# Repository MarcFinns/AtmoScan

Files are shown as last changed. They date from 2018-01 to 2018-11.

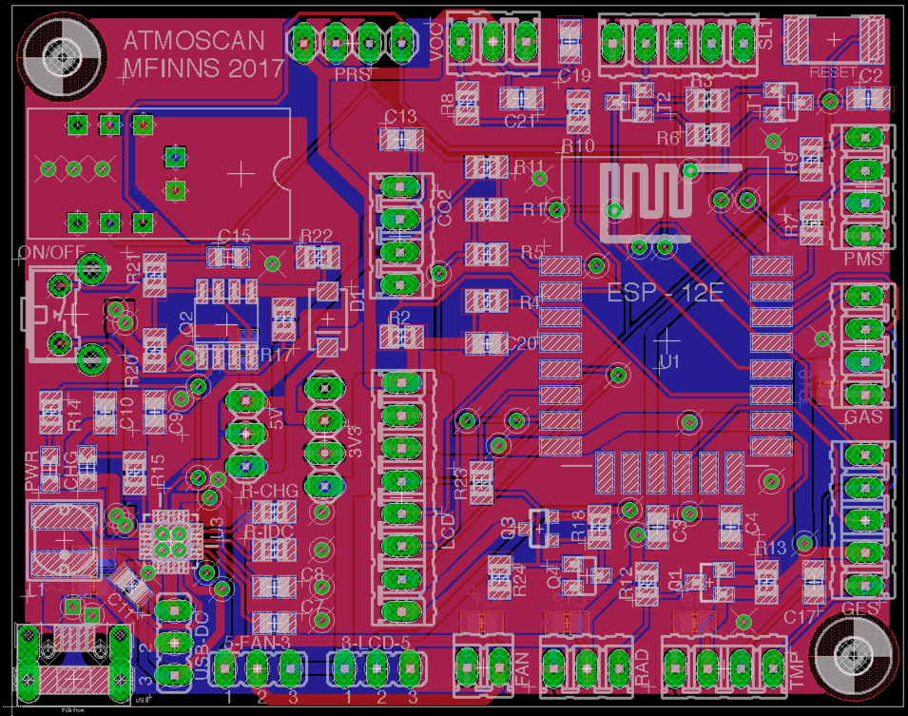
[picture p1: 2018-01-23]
Hardware & Configuration/Atmoscan PCB.jpg

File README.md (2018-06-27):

## AtmoScan

Instructable can be found [HERE](https://www.instructables.com/id/AtmoScan/).  
See it in action in this [VIDEO](https://www.youtube.com/watch?v=iyFuKU8ZcuA).

**What's new** - Atmoscan is evolving:

* Some small hardware changes improved the original design, including the ability to **turn off itself from software**, remediating one of the biggest drawbacks of the design - how to handle low battery. 
* Command added to the setup **menu to turn off the device**
* White screen with low battery issue **mitigation**
* A PCB v2 design is now published together with a guide to easily **apply the change to boards V1.0.**
* Battery pack now based on 5 x 18650 Li-ion in "olympic circles" configuration. Way more performant and reliable than the chinese Li-Po pack
* Repositioning of the CO2 sensor, to completely separate the temperature sensor from any potential heat source
* CAD files for the **complete enclosure**, with improved design

Atmoscan might be (to my knowledge at least) the first ESP8266 application that **uses all GPIOs**, including those that allegedly cannot be used.

**ATMOSCAN** is a multisensor device that measures:

* Temperature
* Humidity
* Pressure
* CO2
* CO
* NO2
* VOC (Air Quality indicator)
* PM 01
* PM25
* PM10
* PM 01
* Radiation

It has an LCD color display, it is gesture controlled and it posts to ThingSpeak (or others) via MQTT, but can properly handle disconnected operations. With a rechargeable battery it lasts a full day when disconnected from power.

It uses a a multitasking cooperative framework and is very responsive to user input while sampling sensors, handling UI, posting to MQTT. I believe it squeezes quite a bit out of the tiny ESP8266...

It integrates a number of open source libraries and leverages internet web services. I started buiding the software with a proper OO application framework in mind and you can find artifacts of it... but never had the time to properly finish it the way i started, so i quickly completed it with way too many hacks. Therefore code could be way better (not properly commented, test code, residuals...).  If anyone is interested in contributing, it's very welcome.

I still have a few PCBs that i am happy to give away to those who want to build it and contribute to it.

### MAIN FEATURES
```
* Color screen
* Gesture control
* Location awareness
* ThingSpeak logging        
* Gracefully handles connected and disconnected operation
* 24h Rechargeable battery
* OTA updates
* Bonus features:
	* Weather Station
	* Plane Spotter

```

### CREDITS

**INCLUDES CODE & LIBRARIES FROM**

```
Adafruit
Arcao
Bblanchon
Bodmer
ClosedCube
Gmag11
Knolleary	
Lucadentella
Seeed
Squix78
Tzapu
Wizard97	
```

**INTEGRATES WEB SERVICES FROM**

```
Adsbexchange.com
GeoNames.org
Google.com
Mylnikov.org
Timezonedb.com
Wunderground.com
```

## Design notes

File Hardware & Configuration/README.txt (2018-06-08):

*IMPORTANT NOTES*

1) HARDWARE
Atmoscan is built with an integrated custom board but can also be built with standard components if you are willing to give up on battery power, size etc. Specifically the prototype was built with only the following components:
- NodeMCU
- Level shifter

2) FLASHING
As the serial port is occupied by a sensor, debugging and programming that way is impractical after assembly as it would require detaching the sensor. Therefore the sketch supports SYSLOG debugging and OTA updates.
The ATMOSCAN binary is over 700Kb and ArduinoOTA requires the program space to be at least twice that size, which rules out the "4M (3M SPIFFS)" option.
However, the standard "4M (1M SPIFFS)" option is also unsuitable as the SPIFFS partition would be insufficient for the graphical resources related to weather station, plane spotter and for the onfing file.
THE SOLUTION: create a custom configuration "4M (2M SPIFFS)".

To do so:
a) Install ESP8266 Arduino support from Github (not from board manager)
b) Add the lines to boards.txt as specified in the accompanying file "mod to boards.txt"
c) Copy the "eagle.flash.4m2m.ld" file to the location ...Arduino/Hardware/esp8266com/esp8266/tools/sdk/ld/
d) Restart Arduino IDE and under NODEMCU 1.0 a new options will appear "4M (2M SPIFFS)"

3) NECESSARY configuration

a) The TFT library (https://github.com/Bodmer/TFT_eSPI) has a config file (User_Setup.h) that MUST be edited to define 
- which GPIOs are used for the display 
- the SPI clock frequency.

While SPI could theoretically run up to 40MHz, it is better to keep it lower, say 20MHz, especially if the cables to the display are not very short. Skipping this step *WILL* make the sketch fail. An example file is in this directory, but make sure you edit your own should the format change in new versions of the library

b) Some #DEFINE statements should be reviewed in the GlobalDefinitions.h file, as follows.

// Used to test board without sensor processes running 
#define ENABLE_SENSORS
 
// Enables the ability to turn itself off. NOTE: requires PCB 2.0 -OR- the appropriate modification 
#define KILL_INSTALLED

// Used to turn on debug log over syslog 
#define DEBUG_SYSLOG
 
// Used to turn on SOME log over serial 
// WARNING - this was used during development and can be used to debug the portions of the sketch that run BEFORE TCP/IP connection is available, but can't be used in the fully assembled system (as serial port is used for a sensor)
#define DEBUG_SERIAL

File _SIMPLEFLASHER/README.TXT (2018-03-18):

This sketch can be used for first flash of the board. Useful to make sure it works, without the complexity of sensors.
1. Configure ESP memory as 4M (2M SPIFFS)
2. Upload this sketch with an FTDI cable connected to the J7 connector
Upon reboot, the board will create a WiFI access point and it accepts OTA updates.

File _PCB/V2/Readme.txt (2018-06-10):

IMPORTANT

The V2 schematic has been tested by modifying a V1 PCB and it works. The V2 PCB has been routed but has not been manufactured. I was happy enough with the modded V1. 
However i thought that if someone wanted to make Atmoscan from scratrch, it would be a good idea to provide the latest schematic with a companion PCB.
THEREFORE... before sending it blindly to your manufacturer of choice, I suggest you double check it.
Please contact me should you find any glitches. 
Happy soldering!

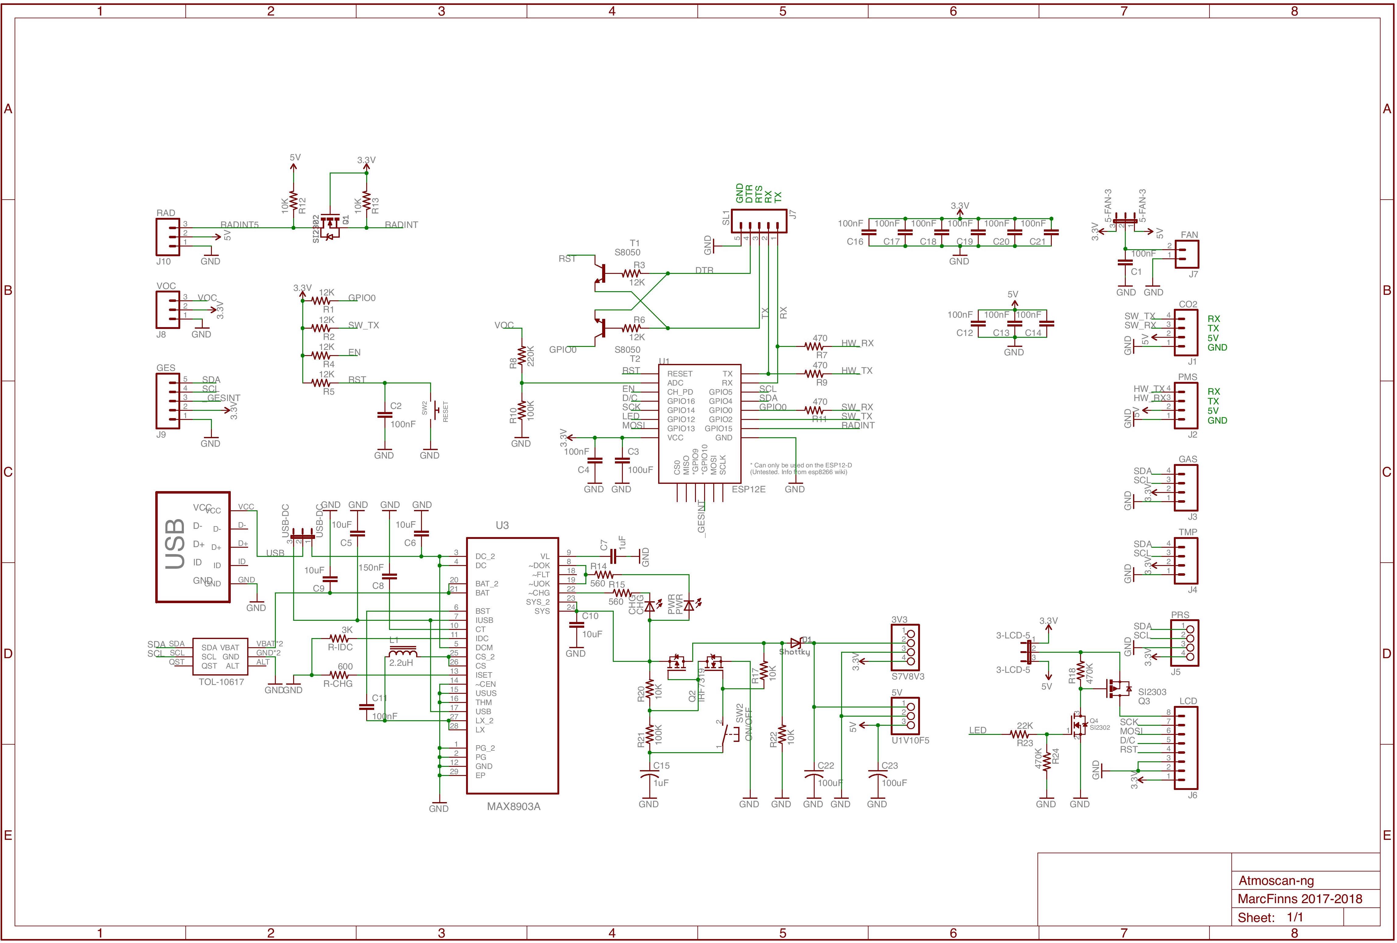
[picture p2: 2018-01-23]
Hardware & Configuration/Atmoscan Schematic.jpeg

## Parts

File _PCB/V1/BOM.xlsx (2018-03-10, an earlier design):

Part | Value | Device | Package | Description
3-LCD-5 | 3-LCD-5 | JP2E | JP2 | JUMPER
3V3 | S7V8V3 | PINHD-1X4 | 1X04 | PIN HEADER
5-FAN-3 | 5-FAN-3 | JP2E | JP2 | JUMPER
5V | U1V10F5 | PINHD-1X3 | 1X03 | PIN HEADER
C1 | 100nF | C-EUC0805 | C0805 | CAPACITOR, European symbol
C2 | 100nF | C-EUC0805 | C0805 | CAPACITOR, European symbol
C3 | 100uF | C-EUC0805 | C0805 | CAPACITOR, European symbol
C4 | 100nF | C-EUC0805 | C0805 | CAPACITOR, European symbol
C5 | 10uF | C-EUC0805 | C0805 | CAPACITOR, European symbol
C6 | 10uF | C-EUC0805 | C0805 | CAPACITOR, European symbol
C7 | 1uF | C-EUC0805 | C0805 | CAPACITOR, European symbol
C8 | 150nF | C-EUC0805 | C0805 | CAPACITOR, European symbol
C9 | 10uF | C-EUC0805 | C0805 | CAPACITOR, European symbol
C10 | 10uF | C-EUC0805 | C0805 | CAPACITOR, European symbol
C11 | 100nF | C-EUC0805 | C0805 | CAPACITOR, European symbol
C12 | 100nF | C-EUC0805 | C0805 | CAPACITOR, European symbol
C13 | 100nF | C-EUC0805 | C0805 | CAPACITOR, European symbol
C14 | 100nF | C-EUC0805 | C0805 | CAPACITOR, European symbol
C15 | 1uF | C-USC0805K | C0805K | CAPACITOR, American symbol
C16 | 100nF | C-EUC0805 | C0805 | CAPACITOR, European symbol
C17 | 100nF | C-EUC0805 | C0805 | CAPACITOR, European symbol
C18 | 100nF | C-EUC0805 | C0805 | CAPACITOR, European symbol
C19 | 100nF | C-EUC0805 | C0805 | CAPACITOR, European symbol
C20 | 100nF | C-EUC0805 | C0805 | CAPACITOR, European symbol
C21 | 100nF | C-EUC0805 | C0805 | CAPACITOR, European symbol
C22 | 100uF | C-USC0805K | C0805K | CAPACITOR, American symbol
C23 | 100uF | C-USC0805K | C0805K | CAPACITOR, American symbol
CHG | CHG | LEDCHIPLED_0805 | CHIPLED_0805 | LED
CO2 | J1 | M04 | 04P | AMP QUICK CONNECTOR
D1 | Shottky | DIODE-SCHOTTKYSMA-403D | SMA-403D | Commonly MBRA140.
FAN | J7 | M02 | 02P | AMP QUICK CONNECTOR
GAS | J3 | M04 | 04P | AMP QUICK CONNECTOR
GES | J9 | M05 | 05P | AMP QUICK CONNECTOR
L1 | 2.2uH | SDR0503 | SDR0503 | POWER INDUCTOR
LCD | J6 | M08 | 08P | AMP QUICK CONNECTOR
ON/OFF | SW2 | 31-XX | B3F-31XX | OMRON SWITCH
PMS | J2 | M04 | 04P | AMP QUICK CONNECTOR
PRS | J5 | PINHD-1X4 | 1X04 | PIN HEADER
PWR | PWR | LEDCHIPLED_0805 | CHIPLED_0805 | LED
Q1 | SI2302 | FET-NMOS-BSS138 | SOT-23
Q2 | IRF7319 | IRF7319 | SO08-IRF | Complimentary Half Bridge HEXFET Power MOSFET
Q3 | SI2303 | NX3008PBK | SOT23-3 | MOSFET - P Channel
Q4 | SI2302 | MOSFET-NREFLOW | SOT23 | N-Channel Mosfet
R-CHG | 600 | R-US_M0805 | M0805 | RESISTOR, American symbol
R-IDC | 3K | R-US_M0805 | M0805 | RESISTOR, American symbol
R1 | 12K | R-US_M0805 | M0805 | RESISTOR, American symbol
R2 | 12K | R-US_M0805 | M0805 | RESISTOR, American symbol
R3 | 12K | R-US_M0805 | M0805 | RESISTOR, American symbol
R4 | 12K | R-US_M0805 | M0805 | RESISTOR, American symbol
R5 | 12K | R-US_M0805 | M0805 | RESISTOR, American symbol
R6 | 12K | R-US_M0805 | M0805 | RESISTOR, American symbol
R7 | 470 | R-US_M0805 | M0805 | RESISTOR, American symbol
R8 | 220K | R-US_M0805 | M0805 | RESISTOR, American symbol
R9 | 470 | R-US_M0805 | M0805 | RESISTOR, American symbol
R10 | 100K | R-US_M0805 | M0805 | RESISTOR, American symbol
R11 | 470 | R-US_M0805 | M0805 | RESISTOR, American symbol
R12 | 10K | R-US_M0805 | M0805 | RESISTOR, American symbol
R13 | 10K | R-US_M0805 | M0805 | RESISTOR, American symbol
R14 | 560 | R-US_M0805 | M0805 | RESISTOR, American symbol
R15 | 560 | R-US_M0805 | M0805 | RESISTOR, American symbol
R17 | 10K | R-US_M0805 | M0805 | RESISTOR, American symbol
R18 | 470K | R-US_M0805 | M0805 | RESISTOR, American symbol
R20 | 10K | R-US_M0805 | M0805 | RESISTOR, American symbol
R21 | 100K | R-US_M0805 | M0805 | RESISTOR, American symbol
R22 | 10K | R-US_M0805 | M0805 | RESISTOR, American symbol
R23 | 22K | R-US_M0805 | M0805 | RESISTOR, American symbol
R24 | 470K | R-US_M0805 | M0805 | RESISTOR, American symbol
RAD | J10 | M03 | 03P | AMP QUICK CONNECTOR
RESET | SW2 | SWITCH_PUSHBUTTONC&K_KSS | BTN_CK_KSS | Buttons
SL1 | J7 | M05 | 05P | AMP QUICK CONNECTOR
T1 | S8050 | BC846 | SOT23 | NPN TRANSISTOR
T2 | S8050 | BC846 | SOT23 | NPN TRANSISTOR
TMP | J4 | M04 | 04P | AMP QUICK CONNECTOR
U1 | ESP12E | ESP12ESMD | ESP12E-SMD | ESP12E Module
U2 | TOL-10617 | TOL-10617 | TOL-10617
U3 | MAX8903A | MAX8903AETI+ | QFN40P400X400X80-29N | 2A 1-Cell Li+ DC-DC Chargers for USB and Adapter Power
USB | MICRO-USB-B | MICRO-USB-B | MICRO_USB_4_LEGS
USB-DC | USB-DC | JP2E | JP2 | JUMPER
VOC | J8 | M03 | 03P | AMP QUICK CONNECTOR

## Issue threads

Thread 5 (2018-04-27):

File missing during compilation

Tokn59, 2018-04-27:
During compilation of the Atmoscan 1.4 sketch the following error is produced :
sketch\esp32-hal-i2c.c:16:23: fatal error: esp32-hal.h: No such file or directory

 #include "esp32-hal.h"

                       ^

compilation terminated.

Multiple libraries were found for "SD.h"
 Used: C:\Users\Tony\AppData\Local\Arduino15\packages\esp8266\hardware\esp8266\2.4.0-rc2\libraries\SD
 Not used: C:\Program Files (x86)\Arduino\libraries\SD
exit status 1
Error compiling for board Generic ESP8266 Module.

Any idea how to solve this ?

Thanks and kind regards,

Tony

per1234, 2018-04-27:
Why do you have a file named esp32-hal-i2c.c in your sketch folder? There is no file of that name in this repository.

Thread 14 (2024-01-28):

VBat conductor shorted to ground on PCB

schofiel, 2024-01-28:
The VBat conductor between the Sparkfun TOL 10617 battery positive pin and the BAT/BAT 2 inputs to the MAX8903A charge management IC U2 (pins 21 & 20) is shorted to ground on the PCB by a flood-filled polygon zone. This is on the top copper layer. The design rule checker does not mark the intersection of the polygon with the track as a problem.

The net result is that U2 (MAX8903A) fails to regulate properly and the board fails to operate (dead short/no voltage). With the battery pack connected, the pack delivers peak current (3x 5A) to ground, with the associated fire risk due to battery failure.

An image of the polygon:

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

An image of the resulting top copper gerber:

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

The work-around is a careful scalpel cut along the edge of the track to separate the polygon from ground.

schofiel, 2024-01-28:
Should note that this is for the V2 board version.

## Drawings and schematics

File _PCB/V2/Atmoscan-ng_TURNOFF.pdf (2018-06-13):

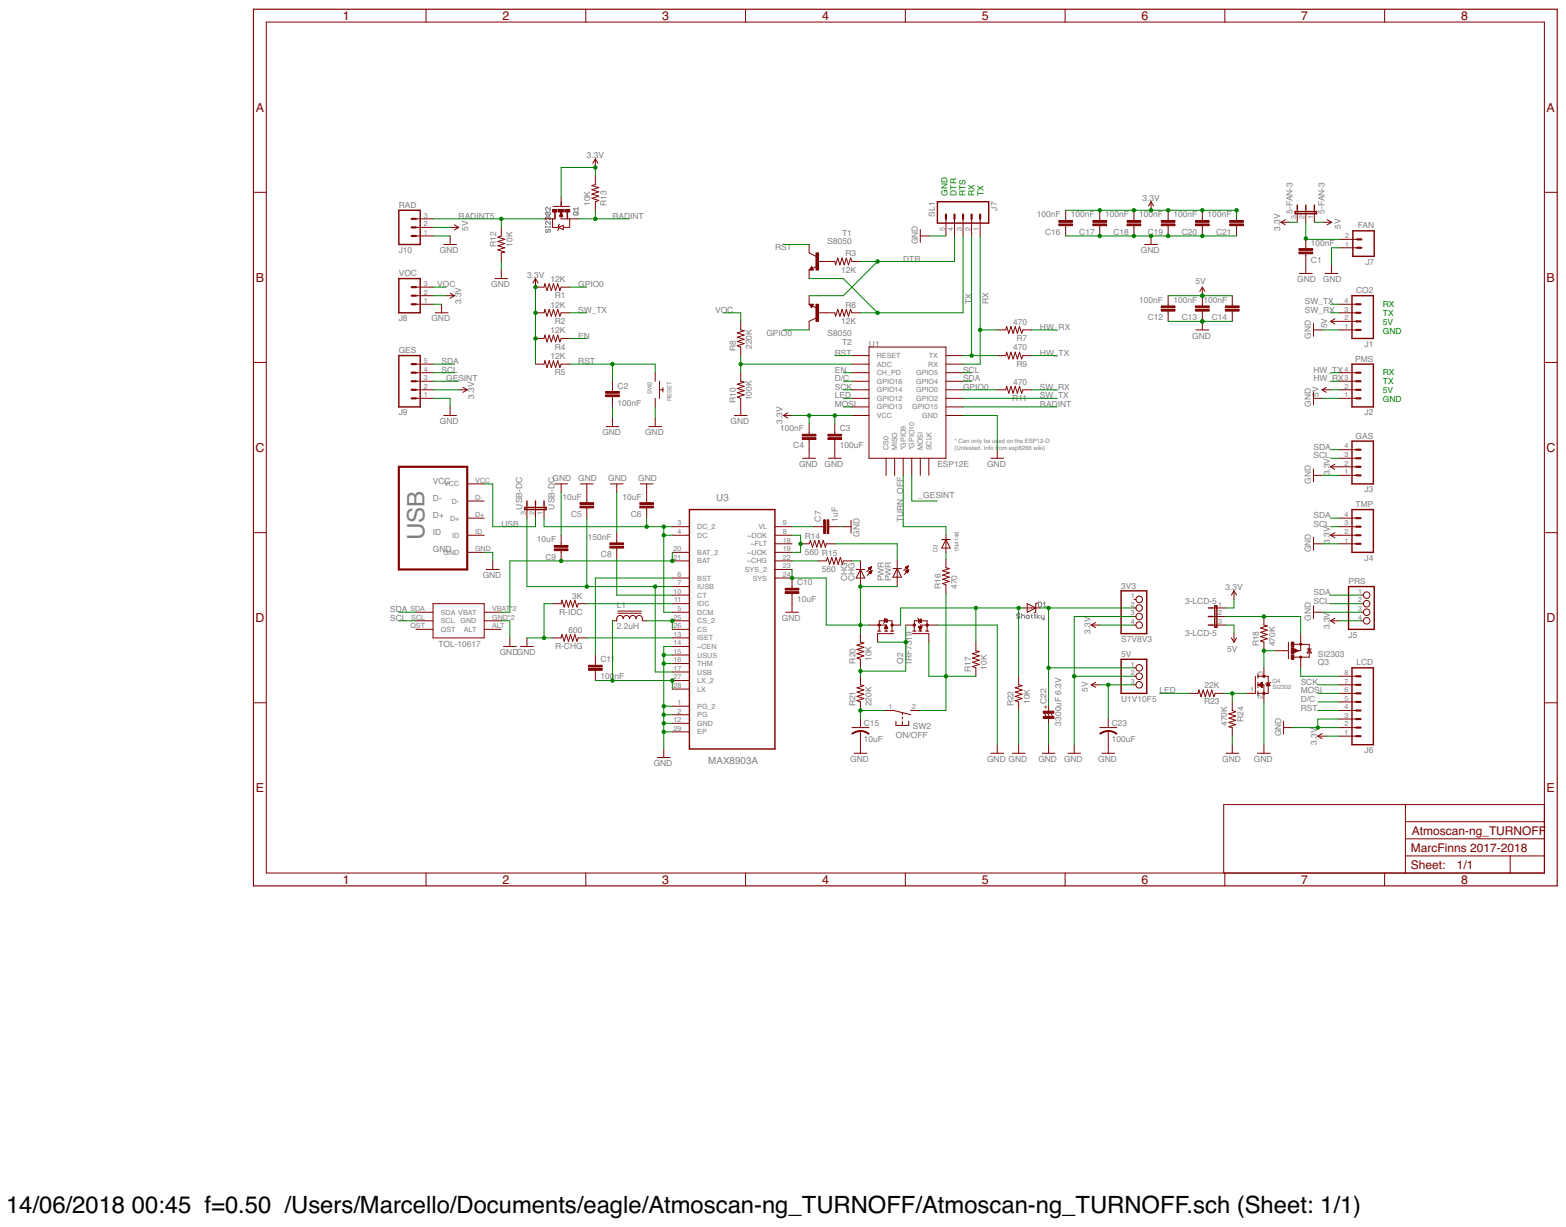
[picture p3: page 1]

* Can only be used on the ESP12-D
(Untested. Info from esp8266 wiki)
ESP12E

14/06/2018 00:45 f=0.50 /Users/Marcello/Documents/eagle/Atmoscan-ng_TURNOFF/Atmoscan-ng_TURNOFF.sch (Sheet: 1/1)

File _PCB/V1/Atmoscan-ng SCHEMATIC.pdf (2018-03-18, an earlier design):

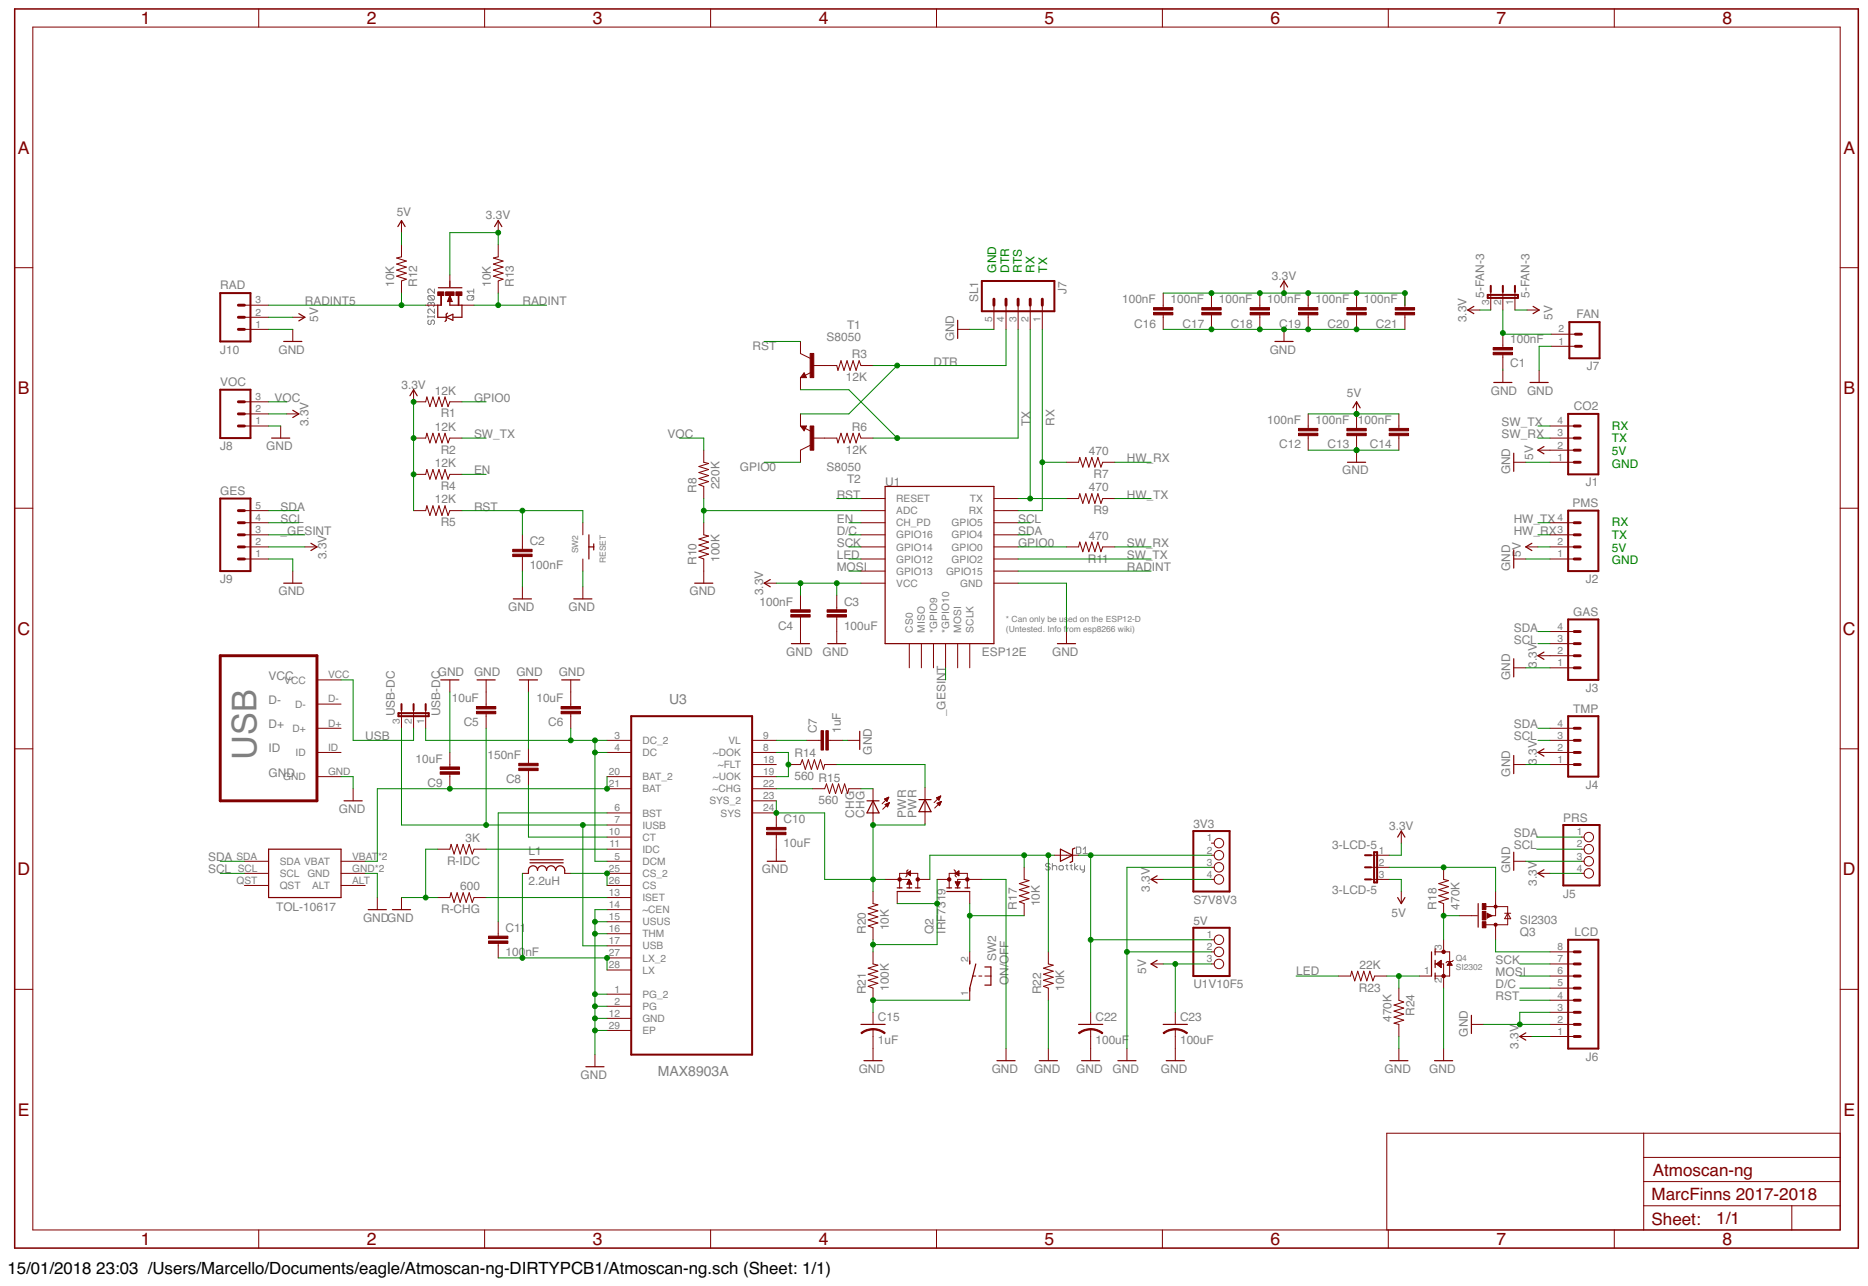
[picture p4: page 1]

* Can only be used on the ESP12-D
(Untested. Info from esp8266 wiki)
ESP12E

15/01/2018 23:03 /Users/Marcello/Documents/eagle/Atmoscan-ng-DIRTYPCB1/Atmoscan-ng.sch (Sheet: 1/1)

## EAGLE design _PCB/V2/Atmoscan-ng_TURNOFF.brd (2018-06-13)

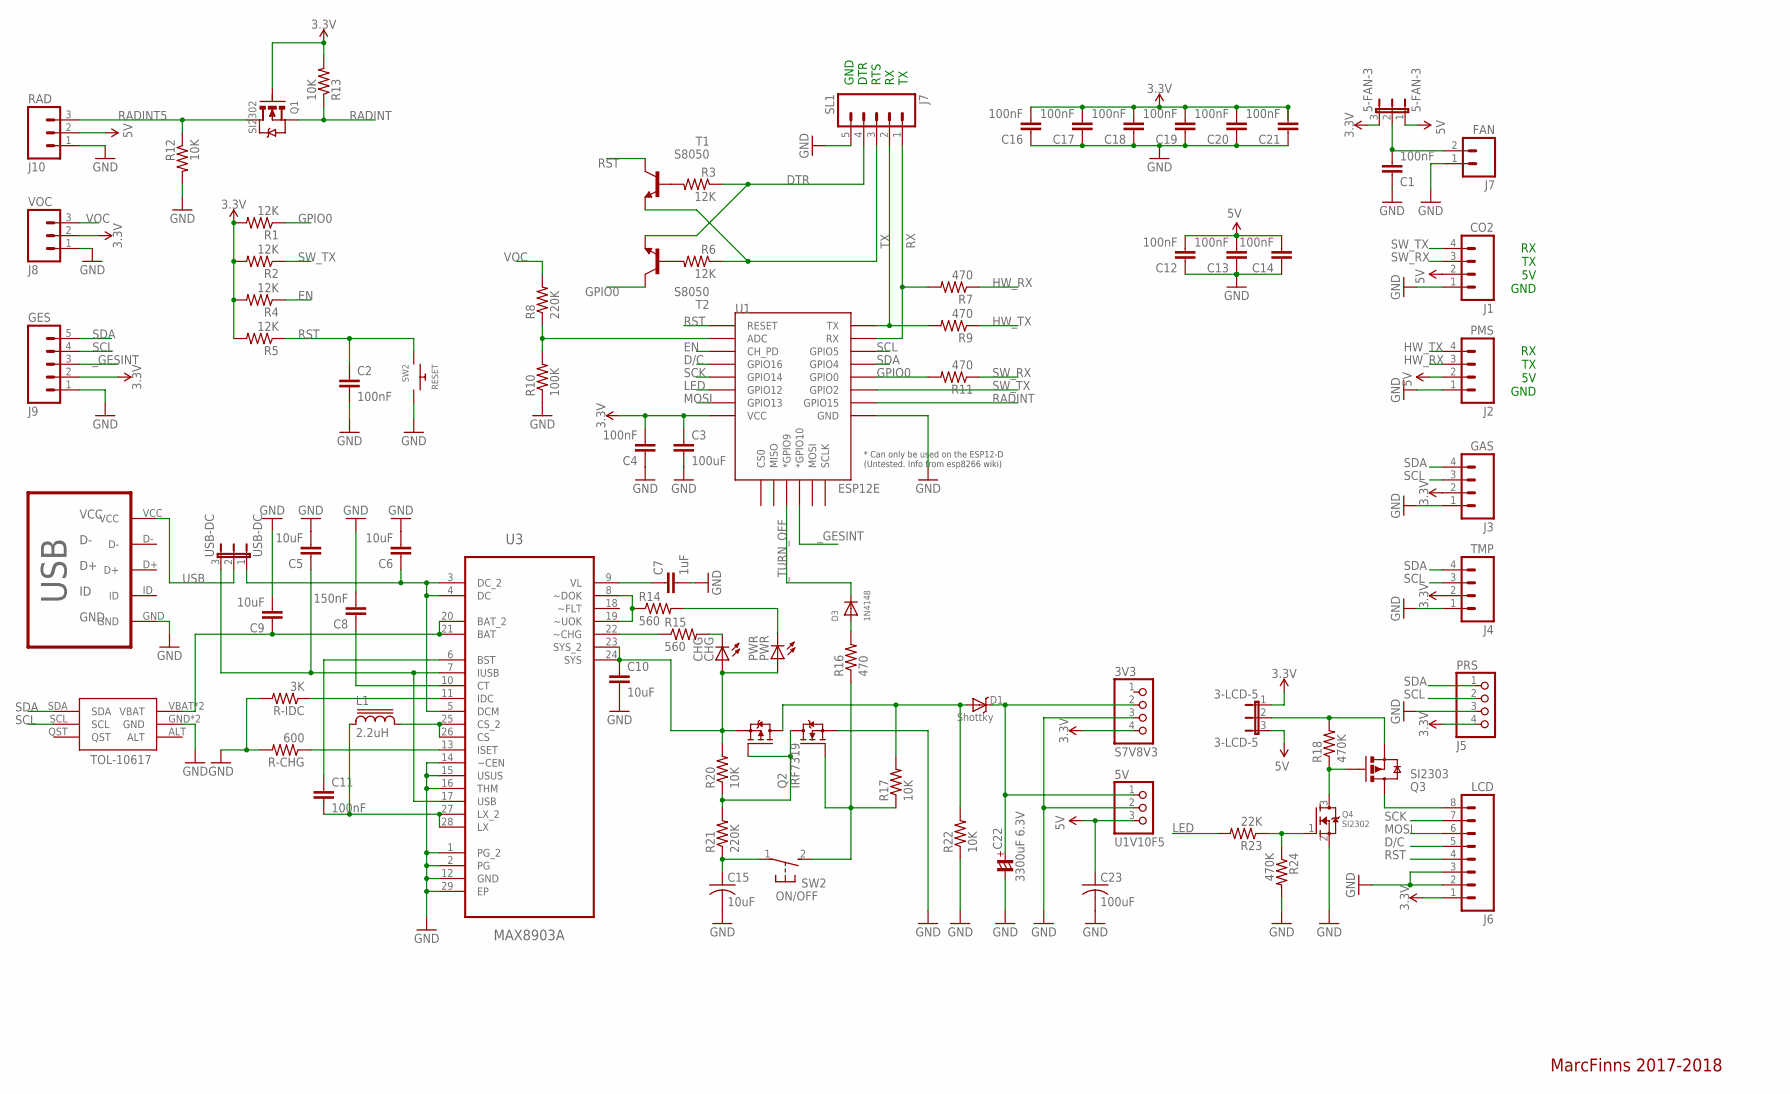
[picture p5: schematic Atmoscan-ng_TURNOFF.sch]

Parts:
3-LCD-5: 3-LCD-5; JP2
3V3: S7V8V3; 1X04
5-FAN-3: 5-FAN-3; JP2
5V: U1V10F5; 1X03
C1, C2, C4, C11, C12, C13, C14, C16, C17, C18, C19, C20, C21: 100nF; C0805
C3: 100uF; C0805
C5, C6, C9, C10: 10uF; C0805
C7: 1uF; C0805
C8: 150nF; C0805
C15: 10uF; C0805K
C22: 3300uF 6.3V; CE-050X100
C23: 100uF; C0805K
CHG: CHG; CHIPLED_0805
CO2: J1; 04P
D1: Shottky; SMA-403D
D3: 1N4148; SOD-123
FAN: J7; 02P
GAS: J3; 04P
GES: J9; 05P
L1: 2.2uH; SDR0503
LCD: J6; 08P
ON/OFF: SW2; B3F-31XX
PMS: J2; 04P
PRS: J5; 1X04
PWR: PWR; CHIPLED_0805
Q1: SI2302; SOT-23
Q2: IRF7319; SO08-IRF
Q3: SI2303; SOT23-3
Q4: SI2302; SOT23
R1, R2, R3, R4, R5, R6: 12K; M0805
R7, R9, R11, R16: 470; M0805
R8, R21: 220K; M0805
R10: 100K; M0805
R12, R13, R17, R20, R22: 10K; M0805
R14, R15: 560; M0805
R18, R24: 470K; M0805
R23: 22K; M0805
R-CHG: 600; M0805
R-IDC: 3K; M0805
RAD: J10; 03P
RESET: SW2; BTN_CK_KSS
SL1: J7; 05P
T1, T2: S8050; SOT23
TMP: J4; 04P
U1: ESP12E; ESP12E-SMD
U2: TOL-10617
U3: MAX8903A; QFN40P400X400X80-29N
USB: MICRO-USB-B; MICRO_USB_4_LEGS
USB-DC: USB-DC; JP2
VOC: J8; 03P

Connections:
3.3V: 3-LCD-5.1, 3V3.4, 5-FAN-3.3, C3.1, C4.2, C16.2, C17.2, C18.2, C19.2, C20.2, C21.2, GAS.2, GES.2, LCD.1, PRS.4, Q1.1 (G), R1.2, R2.2, R4.2, R5.2, R13.2, TMP.2, U1.VCC, VOC.2
5V: 3-LCD-5.3, 5-FAN-3.1, 5V.3, C12.2, C13.2, C14.2, C23.1, CO2.2, PMS.2, RAD.2
ADC: R8.1, R10.2, U1.ADC
D/C: LCD.5, U1.GPIO16
DTR: R3.1, SL1.4, T2.2 (E)
EN: R4.1, U1.CH_PD
GND: 3V3.3, 5V.2, C1.1, C2.2, C3.2, C4.1, C5.2, C6.2, C7.2, C8.2, C9.2, C10.2, C12.1, C13.1, C14.1, C15.2, C16.1, C17.1, C18.1, C19.1, C20.1, C21.1, C22.-, C23.2, CO2.1, FAN.1, GAS.1, GES.1, LCD.2, LCD.3, PMS.1, PRS.3, Q2.1 (N-S), Q4.2 (S), R10.1, R12.2, R22.1, R24.2, R-CHG.2, R-IDC.2, RAD.1, RESET.P$2, SL1.5, TMP.1, U1.GND, U2.GND, U2.GND1 (GND), U3.1 (PG_2), U3.2 (PG), U3.12 (GND), U3.14 (~CEN), U3.15 (USUS), U3.16 (THM), U3.29 (EP), USB.GND, VOC.1
GPIO0: R1.1, R11.2, T2.3 (C), U1.GPIO0
HW_RX: PMS.3, R7.1
HW_TX: PMS.4, R9.1
LED: R23.2, U1.GPIO12
MOSI: LCD.6, U1.GPIO13
unnamed: 3-LCD-5.2, Q3.2 (S), R18.2
unnamed: LCD.8, Q3.3 (D)
unnamed: C15.1, ON/OFF.1, R21.1
unnamed: C11.2, L1.1, U3.27 (LX_2), U3.28 (LX)
unnamed: C11.1, U3.6 (BST)
unnamed: C8.1, U3.10 (CT)
unnamed: Q3.1 (G), Q4.3 (D), R18.1
unnamed: R14.1, U3.8 (~DOK), U3.19 (~UOK)
unnamed: C7.1, U3.9 (VL)
unnamed: R6.2, T2.1 (B)
unnamed: D1.A, Q2.5 (P-D), Q2.6 (P-D), R17.2, R22.2
unnamed: ON/OFF.2 (S), Q2.2 (N-G), R16.1, R17.1
unnamed: Q4.1 (G), R23.1, R24.1
unnamed: R15.1, U3.22 (~CHG)
unnamed: PWR.C, R14.2
unnamed: CHG.C, R15.2
unnamed: L1.2, U3.25 (CS_2), U3.26 (CS)
unnamed: R-CHG.1, U3.13 (ISET)
unnamed: R-IDC.1, U3.11 (IDC)
unnamed: R3.2, T1.1 (B)
unnamed: 5-FAN-3.2, C1.2, FAN.2
unnamed: Q2.4 (P-G), Q2.7 (N-D), Q2.8 (N-D), R20.1, R21.2
unnamed: D3.A, R16.2
RADINT: Q1.2 (S), R13.1, U1.GPIO15
RADINT5: Q1.3 (D), R12.1, RAD.3
RST: C2.1, LCD.4, R5.1, RESET.P$1, T1.3 (C), U1.RESET
RTS: R6.1, SL1.3, T1.2 (E)
RX: R7.2, SL1.1, U1.RXD0 (RX)
SCK: LCD.7, U1.GPIO14
SCL: GAS.3, GES.4, PRS.2, TMP.3, U1.GPIO5, U2.SCL
SDA: GAS.4, GES.5, PRS.1, TMP.4, U1.GPIO4, U2.SDA
SW_RX: CO2.3, R11.1
SW_TX: CO2.4, R2.1, U1.GPIO2
SYS: C10.1, CHG.A, PWR.A, Q2.3 (P-S), R20.2, U3.23 (SYS_2), U3.24 (SYS)
TX: R9.2, SL1.2, U1.TXD0 (TX)
USB: USB.VCC, USB-DC.2
VBAT: C9.1, U2.VBAT, U2.VBAT1 (VBAT), U3.20 (BAT_2), U3.21 (BAT)
VDC: C6.1, U3.3 (DC_2), U3.4 (DC), U3.5 (DCM), USB-DC.1
VOC: R8.2, VOC.3
VUNREG: 3V3.2, 5V.1, C22.+, D1.C
VUSB: C5.1, U3.7 (IUSB), U3.17 (USB), USB-DC.3
_GESINT: GES.3, U1.GPIO10 (*GPIO10)
_TURN_OFF: D3.C, U1.GPIO9 (*GPIO9)

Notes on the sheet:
GND DTR RTS RX TX
RX TX 5V GND
MarcFinns 2017-2018

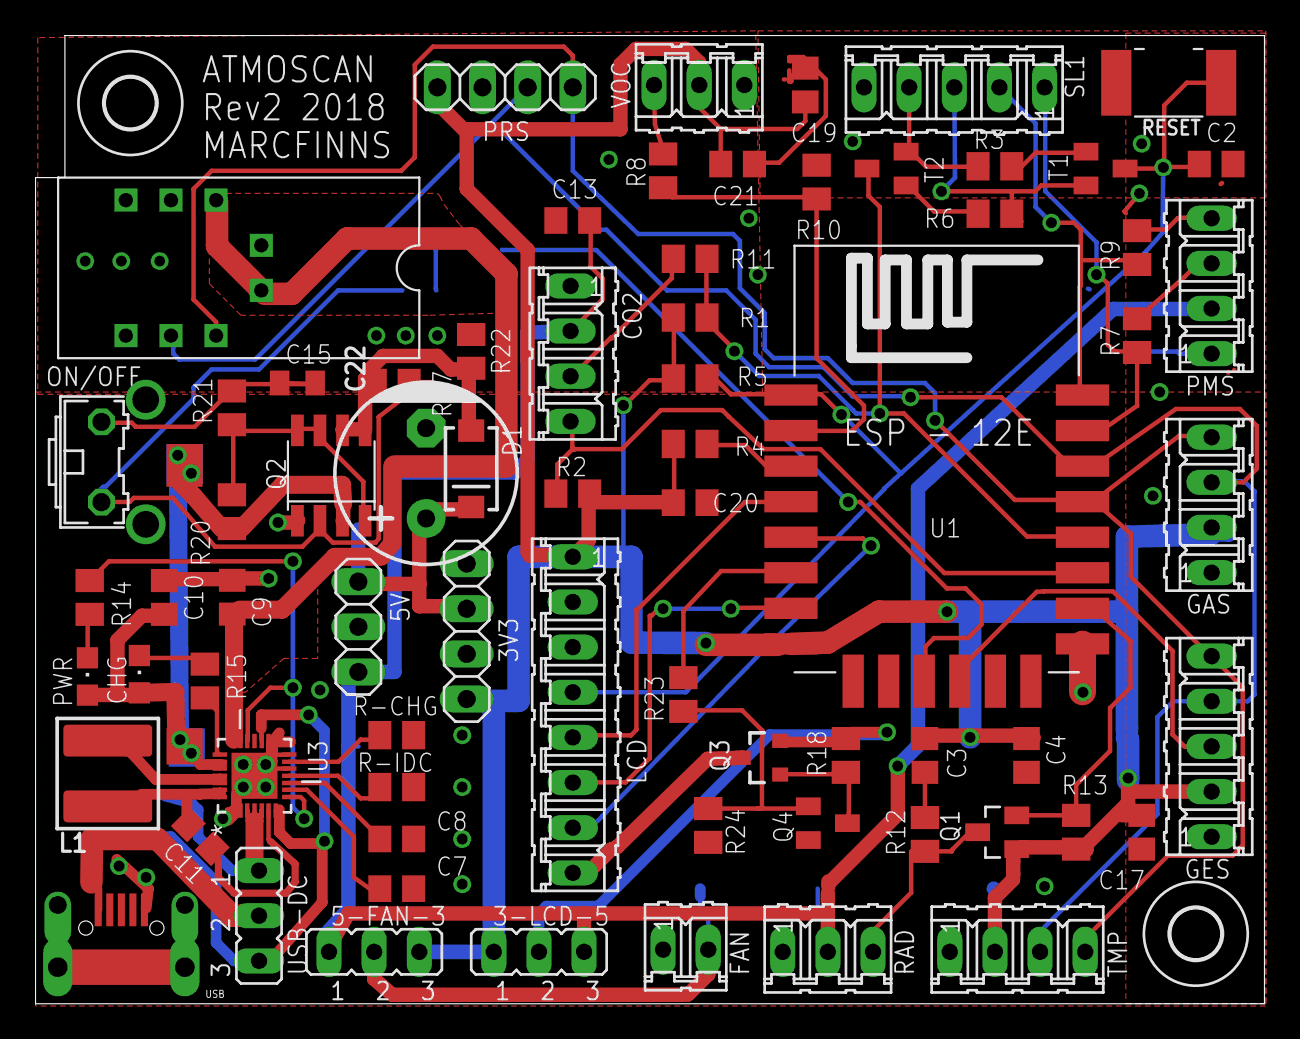
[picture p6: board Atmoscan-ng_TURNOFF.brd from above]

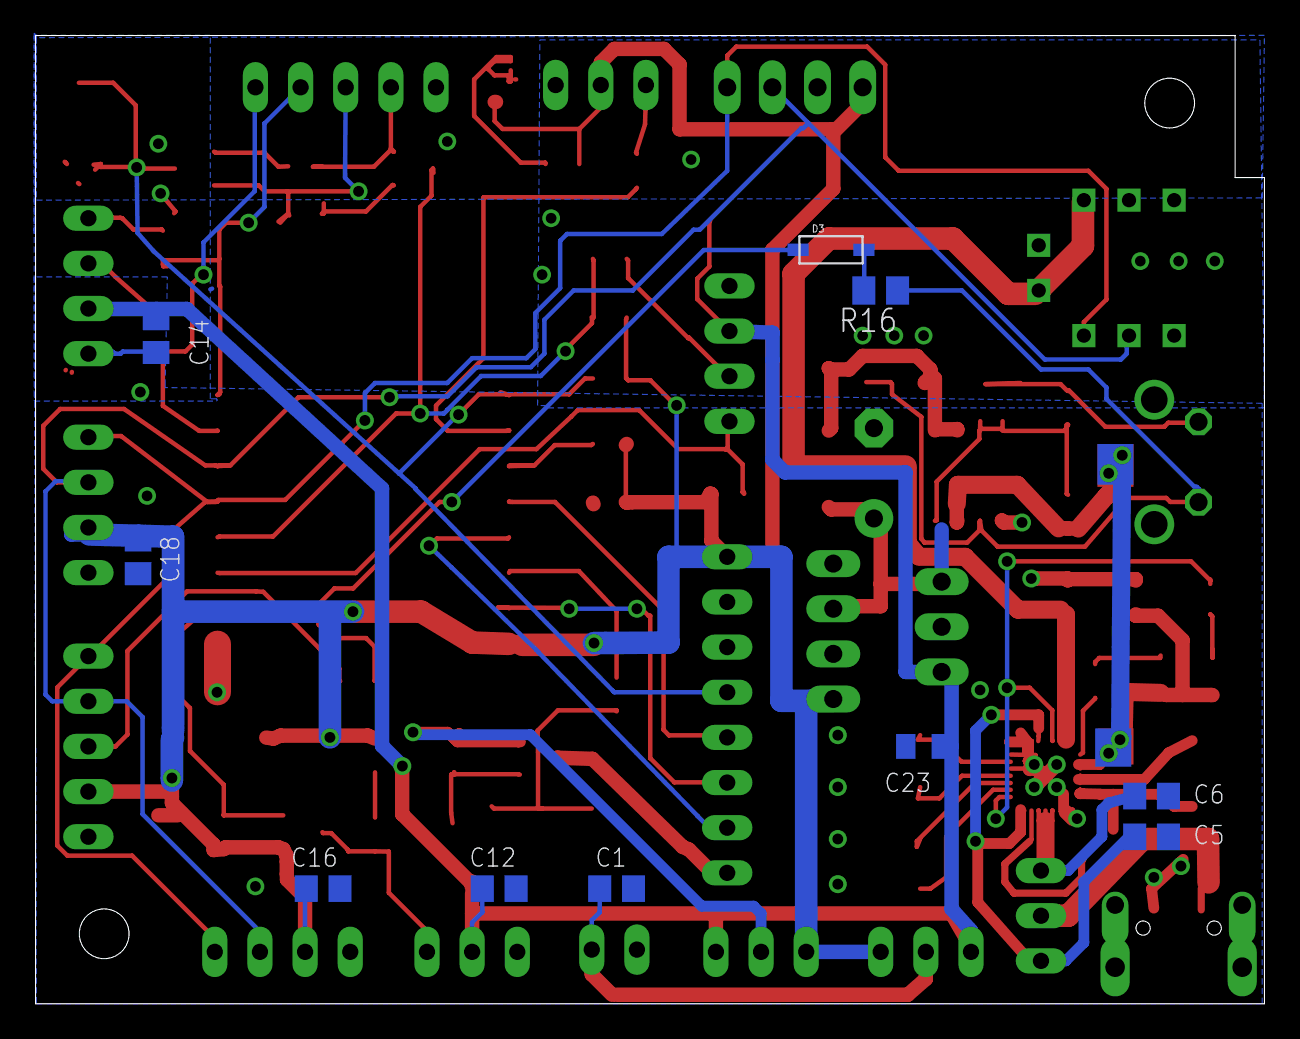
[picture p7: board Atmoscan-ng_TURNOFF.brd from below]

Board: 2 copper layers, 69.1 x 54.5 mm, 83 parts (10 on the bottom side), 55 nets.

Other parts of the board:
U$2, U$4: 2,8

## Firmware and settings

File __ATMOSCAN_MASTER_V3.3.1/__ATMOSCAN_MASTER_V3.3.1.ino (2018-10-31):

/********************************************************/
/*                    ATMOSCAN                          */
/*                                                      */
/* Author: Marc Finns, 2017                             */
/*                                                      */
/*  Components:                                         */
/*      - ESP8266 ESP-12E                               */
/*      - HDC1080 Humidity & Temperature Sensor         */
/*      - Plantower PMS7003 Particle sensor             */
/*      - MZ-H19 CO2 sensor                             */
/*      - Air Quality Sensor (based on Winsen MP503)    */
/*      - Multigas sensor (Based on MiCS6814)           */
/*      - BME 280 Pressure & humidity sensor            */
/*                                                      */
/*  Wiring:                                             */
/*                                                      */
/*  Analog:                                             */
/*      - AirQuality out    => ADC A0                   */
/*  I2C:                                                */
/*      - BMP280    SCL     => GPIO5                    */
/*      - BMP280    SDA     => GPIO4                    */
/*      - HDC1080   SCL     => GPIO5                    */
/*      - HDC1080   SDA     => GPIO4                    */
/*      - PAJ7620U  SCL     => GPIO5                    */
/*      - PAJ7620U  SDA     => GPIO4                    */
/*      - MiCS6814  SCL     => GPIO5                    */
/*      - MiCS6814  SDA     => GPIO4                    */
/*  SPI:                                                */
/*      - ILI9341   SCK     => GPIO14                   */
/*      - ILI9341   MISO    NC                          */
/*      - ILI9341   MOSI    => GPIO13                   */
/*      - ILI9341   D/C     => GPIO16                   */
/*      - ILI9341   RST     => RST                      */
/*      - ILI9341   CS      => GND                      */
/*      - ILI9341   LED     => GPIO12 (via MOS driver)  */
/* Serial:                                              */
/*      - PMS7003   TX      => RXD (GPIO3)              */
/*      - PMS7003   RX      => TXD (GPIO1)              */
/*      - MH-Z19    TX      => GPIO0 (SW RX)            */
/*      - MH-Z19    RX      => GPIO2 (SW TX)            */
/* Interrupts:                                          */
/*      - _Gesture          => GPIO10                   */
/*      - Geiger            => GPIO15                   */
/********************************************************/

// -------------------------------------------------------
// Libraries
// -------------------------------------------------------
#define FS_NO_GLOBALS
#include <FS.h>                   //this needs to be first
#include <ArduinoOTA.h>
#include <ESP8266WiFi.h>
#include <WiFiClient.h>
#include <DNSServer.h>
#include <SPI.h>
#include <Wire.h>

#include <Syslog.h>               // https://github.com/arcao/ESP8266_Syslog
#include <Average.h>              // https://github.com/MajenkoLibraries/Average
#include <PubSubClient.h>         // https://github.com/knolleary/pubsubclient
#include <ProcessScheduler.h>     // https://github.com/wizard97/ArduinoProcessScheduler  NOTE: Requires https://github.com/wizard97/ArduinoRingBuffer
#include <NtpClientLib.h>         // https://github.com/gmag11/NtpClient                  NOTE: Requires https://github.com/PaulStoffregen/Time
#include <ArduinoJson.h>          // https://github.com/bblanchon/ArduinoJson
#include <TFT_eSPI.h>             // https://github.com/Bodmer/TFT_eSPI

// Project includes
#include "GlobalDefinitions.h"
#include "ScreenFactory.h"
#include "TimeSpace.h"

// Screens
#include "ScreenSensors.h"
#include "ScreenStatus.h"
#include "ScreenSetup.h"
#include "ScreenGeiger.h"
#include "ScreenPlaneSpotter.h"
#include "ScreenWeatherStation.h"
#include "ScreenErrLog.h"
#include "ScreenBuienRadar.h"

// Graphics & fonts
#include "GlobalBitmaps.h"
#include "Fonts.h"
#include "Free_Fonts.h"

// Allows to change the clock speed at runtime
extern "C" {
#include "user_interface.h"
}

// -------------------------------------------------------
//  Globals
// -------------------------------------------------------

// Unique board ID
String systemID;

// Turbo flag
bool turbo = false;

// LCD Screen
TFT_eSPI LCD = TFT_eSPI();

// Global UI management
GfxUi ui(&LCD);

WiFiClient wifiClient;

// UDP instance to send and receive packets over UDP
WiFiUDP udpClient;

// Global syslog instance
Syslog syslog(udpClient, SYSLOG_PROTO_IETF);

// Download manager
WebResource webResource;

// Register screens with Screen Factory
ScreenCreatorImpl<ScreenSetup> creator0;
ScreenCreatorImpl<ScreenSensors> creator1;
ScreenCreatorImpl<ScreenStatus> creator2;
ScreenCreatorImpl<ScreenErrLog> creator3;
ScreenCreatorImpl<ScreenGeiger> creator4;
ScreenCreatorImpl<ScreenPlaneSpotter> creator5;
ScreenCreatorImpl<ScreenWeatherStation> creator6;
ScreenCreatorImpl<ScreenBuienRadar> creator7;

// Global Scheduler object
Scheduler sched;

// Last errors list
RingBufCPP<String, 18> lastErrors;

// Configuration container structure
Configuration config;

//  Processes container structure
ProcessContainer procPtr =
{
  Proc_ComboTemperatureHumiditySensor(sched,
  MEDIUM_PRIORITY,
  SLOW_SAMPLE_PERIOD,
  RUNTIME_FOREVER),

  Proc_ComboPressureHumiditySensor(sched,
  MEDIUM_PRIORITY,
  SLOW_SAMPLE_PERIOD,
  RUNTIME_FOREVER),

  Proc_CO2Sensor(sched,
  MEDIUM_PRIORITY,
  SLOW_SAMPLE_PERIOD,
  RUNTIME_FOREVER),

  Proc_ParticleSensor(sched,
  MEDIUM_PRIORITY,
  SLOW_SAMPLE_PERIOD,
  RUNTIME_FOREVER),

  Proc_VOCSensor(sched,
  MEDIUM_PRIORITY,
  SLOW_SAMPLE_PERIOD,
  RUNTIME_FOREVER),

  Proc_MultiGasSensor(sched,
  MEDIUM_PRIORITY,
  SLOW_SAMPLE_PERIOD,
  RUNTIME_FOREVER),

  Proc_GeigerSensor(sched,
  MEDIUM_PRIORITY,
  FAST_SAMPLE_PERIOD,
  RUNTIME_FOREVER),

  Proc_UIManager(sched,
  HIGH_PRIORITY,
  SLOW_SAMPLE_PERIOD,
  RUNTIME_FOREVER),

  Proc_MQTTUpdate(sched,
  MEDIUM_PRIORITY,
  MQTT_UPDATE_PERIOD,
  RUNTIME_FOREVER),

  Proc_GeoLocation(sched,
  MEDIUM_PRIORITY,
  GEOLOC_RETRY_PERIOD,
  RUNTIME_FOREVER)

};

void setup()
{

#ifdef DEBUG_SERIAL
  Serial.begin(115200);
#endif

  // Wait for electronics to settle
  delay(3000);

  // Dynamically create systemID based on MAC address
  systemID = F("ATMOSCAN-");
  systemID += WiFi.macAddress();
  systemID.replace(F(":"), F(""));

  // Initiatlise the LCD
  LCD.begin();
  LCD.setRotation(2);
  LCD.fillScreen(TFT_BLACK);


  // Initialise text engine
  LCD.setTextColor(TFT_WHITE, TFT_BLACK);
  LCD.setTextWrap(false);
  LCD.setFreeFont(FSS9);
  int  xpos = 0;
  int  ypos = 20;
  LCD.setTextDatum(BR_DATUM);

  // **********************  Draw splash screen
  ui.drawBitmap(Splash_Screen, (LCD.width() - splashWidth) / 2, 20, splashWidth, splashHeight);

  LCD.drawString(F(ATMOSCAN_VERSION), xpos, ypos, GFXFF);

  xpos = 240;
  LCD.setTextDatum(BL_DATUM);
  LCD.drawString(F("(c) 2018 MarcFinns"), xpos, ypos, GFXFF);

  // **********************  Credits: Libraries
  ypos = 215;

  LCD.drawRect(0, ypos, 240, 105, TFT_WHITE);
  LCD.setFreeFont(&Dialog_plain_9);

  ypos += 13;
  int lineSpacing = 9;

  LCD.setTextDatum(BC_DATUM);
  LCD.drawString(F("INCLUDES LIBRARIES FROM:"), 120, ypos, GFXFF);

  LCD.setTextDatum(BL_DATUM);

  ypos +=  lineSpacing + 6;
  LCD.drawString(F("Adafruit"), 6, ypos, GFXFF);
  LCD.drawString(F("ClosedCube"), 85, ypos, GFXFF);
  LCD.drawString(F("Seeed"), 170, ypos, GFXFF);

  ypos +=  lineSpacing;
  LCD.drawString(F("Arcao"), 6, ypos, GFXFF);
  LCD.drawString(F("Gmag11"), 85, ypos, GFXFF);
  LCD.drawString(F("Squix78"), 170, ypos, GFXFF);

  ypos +=  lineSpacing;
  LCD.drawString(F("Bblanchon"), 6, ypos, GFXFF);
  LCD.drawString(F("Knolleary"), 85, ypos, GFXFF);
  LCD.drawString(F("Tzapu"), 170, ypos, GFXFF);

  ypos +=  lineSpacing;
  LCD.drawString(F("Bodmer"), 6, ypos, GFXFF);
  LCD.drawString(F("Lucadentella"), 85, ypos, GFXFF);
  LCD.drawString(F("Wizard97"), 170, ypos, GFXFF);


  // ********************* Credits: web services
  ypos +=  lineSpacing + 6;

  LCD.setTextDatum(BC_DATUM);
  LCD.drawString(F("INTEGRATES WEB SERVICES FROM:"), 120, ypos, GFXFF);

  LCD.setTextDatum(BL_DATUM);

  ypos +=  lineSpacing + 6;
  LCD.drawString(F("Adsbexchange.com"), 6, ypos, GFXFF);
  LCD.drawString(F("GeoNames.org"), 122, ypos, GFXFF);

  ypos +=  lineSpacing;
  LCD.drawString(F("Google.com"), 6, ypos, GFXFF);
  LCD.drawString(F("Wunderground.com"), 122, ypos, GFXFF);

  ypos +=  lineSpacing;
  LCD.drawString(F("Timezonedb.com"), 6, ypos, GFXFF);
  LCD.drawString(F("Mylnikov.org"), 122, ypos, GFXFF);

  /////////////////////////////////////////////////////
  // clean SPIFFS FS, used for testing
  // SPIFFS.format();
  /////////////////////////////////////////////////////

  // Initialise I2C bus
  Wire.begin(I2C_SDA_PIN, I2C_SCL_PIN);

  // Add process objects to scheduler
  addProcesses();

  // Turn on LCD and wait a bit on splash screen...
  procPtr.UIManager.displayOn();
  delay (1000);

  // **********************  Initialization with progress bar...
  LCD.setFreeFont(FSS9);
  LCD.setTextDatum(TL_DATUM);
  LCD.setTextColor(TFT_YELLOW, TFT_BLACK);
  xpos = 6;
  ypos = 195;

  // Retrieve dynamic config parameters from SPIFSS (such as MQTT Topics and servers)

  // Draw progress bar...
  ui.drawProgressBar(10, 175, 240 - 20, 15, 0, TFT_YELLOW, TFT_BLUE);

  // Show init step...
  LCD.drawString(F("Retrieving configuration...       "), xpos, ypos, GFXFF);
  ui.drawProgressBar(10, 175, 240 - 20, 15, 30, TFT_YELLOW, TFT_BLUE);

  delay(500);

  // Retrieve configuration from SPIFFS, if existent
  if (retrieveConfig())
  {
    config.configValid = true;

    // Show init step...
    LCD.drawString(F("Connecting to network...    "), xpos, ypos, GFXFF);
    ui.drawProgressBar(10, 175, 240 - 20, 15, 60, TFT_YELLOW, TFT_BLUE);

    delay(500);

    // Handle Wifi connection, including dynamic config parameters such as MQTT Topic and server
    config.connected = wifiConnect();

    // Initialize NTP library
    initNTP();

    //  Configure syslog instance
    syslog.server(config.syslog_server, SYSLOG_PORT);
    syslog.deviceHostname(systemID.c_str());
    syslog.appName(APP_NAME);
    syslog.defaultPriority(LOG_KERN);

    // Start logging
    delay(200);
    String strBuffer = F("******* BOOTING FIRMWARE ") ;
    syslog.log(LOG_INFO, strBuffer + F(ATMOSCAN_VERSION) + F(", BUILT ") + String(__DATE__ " " __TIME__) + F(" ******* "));

    // Log current configuration
    strBuffer = F("Connected to network ");
    syslog.log(LOG_INFO, strBuffer + WiFi.SSID() + F(" with address ") + WiFi.localIP().toString());

    // Scan I2C bus and log devices found
#ifdef DEBUG_SYSLOG
    delay(1000); // Syslog does not like too many messages at a time...
    i2cScan();
#endif

    // Log current AtmoScan configuration
#ifdef DEBUG_SYSLOG
    delay(1000); // Syslog does not like too many messages at a time...
    syslog.log(LOG_DEBUG, F("Configuration is:"));
    syslog.log(LOG_DEBUG, config.mqtt_server);
    syslog.log(LOG_DEBUG, config.mqtt_topic1);
    syslog.log(LOG_DEBUG, config.mqtt_topic2);
    syslog.log(LOG_DEBUG, config.syslog_server);
    syslog.log(LOG_DEBUG, config.google_key);
    syslog.log(LOG_DEBUG, config.wunderground_key);
    syslog.log(LOG_DEBUG, config.geonames_user);
    syslog.log(LOG_DEBUG, config.timezonedb_key);
#endif

#ifdef DEBUG_SERIAL
    Serial.println(F("Configuration is:"));
    Serial.println(config.mqtt_server);
    Serial.println(config.mqtt_topic1);
    Serial.println(config.mqtt_topic2);
    Serial.println(config.syslog_server);
    Serial.println(config.google_key);
    Serial.println(config.wunderground_key);
    Serial.println(config.geonames_user);
    Serial.println(config.timezonedb_key);

#endif

    // Log ESP configuration
#ifdef DEBUG_SYSLOG
    logESPconfig();

    // log SPIFFS usage
    listFiles();
#endif
  }
  else
  {
    // If no valid config found, force Setup screen
    config.configValid = false;
    config.startScreen = SETUP_SCREEN;
  }

  // Initialise OTA
  initOTA();

  // Show init step...
  LCD.drawString(F("Starting processes...         "), xpos, ypos, GFXFF);
  ui.drawProgressBar(10, 175, 240 - 20, 15, 100, TFT_YELLOW, TFT_BLUE);

  // Start processes
  startProcesses();

  // Wait a bit (optical)
  delay(500);

  // Configuration completed!
  syslog.log(LOG_INFO, F("************ BOOT SEQUENCE COMPLETE *************"));

  ESP.wdtEnable(0);
}

void loop()
{

  // Handle OTA
  ArduinoOTA.handle();

  // Invoke scheduler
  sched.run();

  // Feed the WatchDog
  ESP.wdtFeed();

}


// OTA firmware update management

int lastOTAprogressPercentual = 0;

void initOTA()
{
  // Port defaults to 8266
  ArduinoOTA.setPort(8266);

  // Set Hostname
  ArduinoOTA.setHostname(systemID.c_str());

  // Default password
  ArduinoOTA.setPassword((const char *)"ATMOSCAN");

  ArduinoOTA.onStart([]()
  {
    // Precautionary display reset
    LCD.init();

    delay(100);

    // Turn on backlight
    procPtr.UIManager.displayOn();

    // Reset screen settings
    LCD.setRotation(2);
    LCD.fillScreen(TFT_BLUE);
    LCD.setTextColor(TFT_YELLOW, TFT_BLUE);
    LCD.setFreeFont(FSS9);
    LCD.setTextDatum(BC_DATUM);
    LCD.drawString(F("OTA Firmware update"), 120, 20, GFXFF);
    syslog.log(LOG_INFO, F("OTA Update Start"));
  });

  ArduinoOTA.onEnd([]()
  {
    LCD.setTextDatum(BL_DATUM);
    LCD.drawString(F(" Rebooting..."), 0, 120, GFXFF);
    syslog.log(LOG_INFO, F("OTA Update End - Rebooting"));
    delay(500);
    ESP.restart();
  });


  ArduinoOTA.onProgress([](unsigned int progress, unsigned int total)
  {

    int progressPercentual = progress / (total / 100.0);

    // Print OTA progress only if incremented
    if (progressPercentual != lastOTAprogressPercentual)
    {
      // Print OTA progress

      LCD.drawString(String(progress) + F("/") + String (total) + F(" bytes (") + String(progressPercentual) + F("%)"), 120, 50, GFXFF);
      syslog.logf(LOG_INFO, "OTA Progress = %u%%\r", progressPercentual);

      ui.drawProgressBar(10, 60, 240 - 20, 15, progressPercentual, TFT_YELLOW, TFT_YELLOW);
      lastOTAprogressPercentual = progressPercentual;
    }
  });

  ArduinoOTA.onError([](ota_error_t error)
  {
    //String strbuffer = F("OTA Update Error ");
    syslog.log(LOG_ERR, "OTA Update Error " +   String(error));
    if (error == OTA_AUTH_ERROR)
    {
      LCD.drawString(F("OTA Auth Failed"), 0, 100, GFXFF);
      errLog(F("OTA Auth Failed"));
    }
    else if (error == OTA_BEGIN_ERROR)
    {
      LCD.drawString(F("OTA Update Begin Failed"), 0, 100, GFXFF);
      errLog( F("OTA Update Begin Failed"));
    }
    else if (error == OTA_CONNECT_ERROR)
    {
      LCD.drawString(F("OTA Update Connect Failed"), 0, 100, GFXFF);
      errLog( F("OTA Update Connect Failed"));
    }
    else if (error == OTA_RECEIVE_ERROR)
    {
      LCD.drawString(F("OTA Update Receive Failed"), 0, 100, GFXFF);
      errLog( F("OTA Update Receive Failed"));
    }
    else if (error == OTA_END_ERROR)
    {
      LCD.drawString(F("OTA Update End Failed"), 0, 100, GFXFF);
      errLog( F("OTA Update End Failed"));
    }

    delay(2000);
    ESP.restart();
  });

  // OTA name Setup
  ArduinoOTA.setHostname((const char *)systemID.c_str());

  // Begin listening
  ArduinoOTA.begin();
}

// Manage network disconnection
void onSTADisconnected(WiFiEventStationModeDisconnected event_info)
{

#ifdef DEBUG_SERIAL
  Serial.println("WiFi disconnected");
#endif

  config.connected = false;
}


// Manage network reconnection
void onSTAGotIP(WiFiEventStationModeGotIP ipInfo)
{
#ifdef DEBUG_SERIAL
  Serial.println("WiFi Connected");
#endif

  // Remember current connection status in configuration
  config.connected =  true;
}


// Network time management
void initNTP()
{
  static WiFiEventHandler e1, e2;

  // NTP start
  NTP.onNTPSyncEvent([](NTPSyncEvent_t error)
  {
    if (error)
    {
      if (error == noResponse)
      {
        errLog(F("NTP svr unreachable"));
      }
      else if (error == invalidAddress)
      {
        errLog(F("Invalid NTP server address"));
      }
    }
    else
    {
      String strBuffer = F("Got NTP time - ") ;
      syslog.log(LOG_INFO, strBuffer + NTP.getTimeDateString(NTP.getLastNTPSync()));
    }
  });

  e1 = WiFi.onStationModeGotIP(onSTAGotIP);
  e2 = WiFi.onStationModeDisconnected(onSTADisconnected);
}

// Add processes to scheduler
void addProcesses()
{

#ifdef ENABLE_SENSORS
  procPtr.ComboTemperatureHumiditySensor.add();
  procPtr.ComboPressureHumiditySensor.add();
  procPtr.CO2Sensor.add();
  procPtr.ParticleSensor.add();
  procPtr.VOCSensor.add();
  procPtr.MultiGasSensor.add();
  procPtr.GeigerSensor.add();
  procPtr.MQTTUpdate.add();
#endif

  procPtr.UIManager.add();
  procPtr.GeoLocation.add();
}

// Enable Process scheduling
void startProcesses()
{
  // if current configuration is not valid, start UI only
  if (config.configValid)
  {
#ifdef ENABLE_SENSORS
    procPtr.ComboTemperatureHumiditySensor.enable();
    procPtr.ComboPressureHumiditySensor.enable();
    procPtr.ParticleSensor.enable();
    procPtr.CO2Sensor.enable();
    procPtr.VOCSensor.enable();
    procPtr.MultiGasSensor.enable();
    procPtr.GeigerSensor.enable();
    procPtr.MQTTUpdate.enable();
#endif
    procPtr.GeoLocation.enable();
  }
  else
  {
#ifdef DEBUG_SYSLOG
    syslog.log(LOG_INFO, F("Invalid configuration, starting only UI process"));
#endif
  }

  procPtr.UIManager.enable();

}

// Retrieve previously saved configuration from SPIFFS
bool retrieveConfig()
{
  // Read configuration from FS json
  if (SPIFFS.begin())
  {
    if (SPIFFS.exists(F("/config.json")))
    {
#ifdef DEBUG_SERIAL
      Serial.println("Configuration found");
#endif

      //file exists, read and load it
      fs::File configFile = SPIFFS.open(F("/config.json"), "r");
      if (configFile)
      {
        size_t size = configFile.size();

        // Allocate a buffer to store contents of the file.
        std::unique_ptr<char[]> buf(new char[size]);

        configFile.readBytes(buf.get(), size);
        DynamicJsonBuffer jsonBuffer;
        JsonObject &json = jsonBuffer.parseObject(buf.get());

        if (json.success())
        {

#ifdef DEBUG_SERIAL
          Serial.println("JSON parse success ");
#endif

          // Gracefully handle upgrade from firmware v1.x
          if (!json.containsKey(F("google_key")))
          {
            syslog.log(LOG_ERR, F("Incompatible configuration found"));
            return false;
          }

          strcpy(config.mqtt_server, json[F("mqtt_server")]);
          strcpy(config.mqtt_topic1, json[F("mqtt_topic1")]);
          strcpy(config.mqtt_topic2, json[F("mqtt_topic2")]);
          strcpy(config.mqtt_topic3, json[F("mqtt_topic3")]);
          strcpy(config.syslog_server, json[F("syslog_server")]);
          strcpy(config.google_key, json[F("google_key")]);
          strcpy(config.wunderground_key, json[F("wunderground_key")]);
          strcpy(config.geonames_user, json[F("geonames_user")]);
          strcpy(config.timezonedb_key, json[F("timezonedb_key")]);
          return true;

        }
        else
        {
#ifdef DEBUG_SERIAL
          Serial.println("JSON parse failed ");
#endif
          // LCD.print(F(" Error parsing"));
          delay(2000);
          SPIFFS.format();
          ESP.eraseConfig();
          return false;
        }
      }
    }
    else
    {
#ifdef DEBUG_SERIAL
      Serial.println(F("JSON File does not exist!"));
#endif
      delay(2000);
      ESP.eraseConfig();
      return false;
    }
  }
  else
  {
    LCD.println(F(" > Could not access file system"));
#ifdef DEBUG_SERIAL
    Serial.println(F("Could access file system!"));
#endif
    return false;
  }
}


// Connect to WiFi
bool wifiConnect()
{
  // Connect using last good credentials
  WiFi.mode(WIFI_STA);
  WiFi.begin();

  // Set hostname
  WiFi.hostname(systemID);

  // Wait for connection...
  int counter = 0;
  while (WiFi.status() != WL_CONNECTED && counter++ < 30)
  {
    delay(500);
  }
  if (WiFi.status() == WL_CONNECTED )
  {
    return true;
  }
  else
  {
    return false;
  }
}


#ifdef DEBUG_SYSLOG
void logESPconfig()
{

  syslog.log(LOG_DEBUG, F("FLASH CONFIGURATION LOG"));
  // Log ESP configuration
  uint32_t realSize = ESP.getFlashChipRealSize();
  uint32_t ideSize = ESP.getFlashChipSize();
  FlashMode_t ideMode = ESP.getFlashChipMode();
  delay(1000);
  syslog.logf(LOG_DEBUG, "Flash real id:   %08X\n", ESP.getFlashChipId());
  delay(1000);
  syslog.logf(LOG_DEBUG, "Flash real size: %u\n\n", realSize);
  delay(1000);
  syslog.logf(LOG_DEBUG, "Flash ide  size: %u\n", ideSize);
  delay(1000);
  syslog.logf(LOG_DEBUG, "Flash ide speed: %u\n", ESP.getFlashChipSpeed());
  delay(1000);
  syslog.logf(LOG_DEBUG, "Flash ide mode:  %s\n", (ideMode == FM_QIO ? "QIO" : ideMode == FM_QOUT ? "QOUT" : ideMode == FM_DIO ? "DIO" : ideMode == FM_DOUT ? "DOUT" : "UNKNOWN"));
  delay(1000);
  if (ideSize != realSize)
  {
    errLog( F("Flash Chip configuration wrong!"));
  }
  else
  {
    syslog.log(LOG_DEBUG, F("Flash Chip configuration ok."));
  }
}
#endif

// Allows to dynamically set CPU clock (80 or 160 MHz)
void setTurbo(bool setTurbo)
{
  if (setTurbo)
  {
#ifdef DEBUG_SYSLOG
    syslog.log(LOG_DEBUG, F("Set TURBO mode"));
#endif
    system_update_cpu_freq(160);
    turbo = true;
  }
  else
  {
#ifdef DEBUG_SYSLOG
    syslog.log(LOG_DEBUG, F("Set NORMAL mode"));
#endif
    system_update_cpu_freq(80);
    turbo = false;
  }

}

// Check current CPU clock status
bool isTurbo()
{
  return turbo;
}
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

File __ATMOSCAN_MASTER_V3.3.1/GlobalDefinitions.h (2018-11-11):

/********************************************************/
/*                    ATMOSCAN                          */
/*                                                      */
/*            Author: Marc Finns 2017                   */
/*                                                      */
/********************************************************/

//#pragma once

#ifndef GLOBALDEFINITIONS_H
#define GLOBALDEFINITIONS_H

#include <RingBufCPP.h>           //https://github.com/wizard97/Embedded_RingBuf_CPP
#include "P_UIManager.h"
#include "P_MQTT.h"
#include "P_AirSensors.h"
#include "P_GeoLocation.h"
#include "WundergroundClient.h"

// -------------------------------------------------------
// Definitions
// -------------------------------------------------------

// Used to turn on debug log over syslog
// #define DEBUG_SYSLOG

// Used to turn on SOME log over serial
// WARNING - this was used during development but can't be used in the fully assembled system, as serial port is used for a sensor
// #define DEBUG_SERIAL

// Used to test board without sensor processes running
#define ENABLE_SENSORS

// Enables the ability to turn itself off. NOTE: requires PCB 2.0 -OR- the appropriate modification
NOTE: COMPILATION ERROR INTENTIONAL... PLEASE COMMENT OUT THE FOLLOWING LINE IF HARDWARE MOD NOT PRESENT!!!
#define KILL_INSTALLED

// Firmware revision
#define ATMOSCAN_VERSION "v3.3.1"

// This system name
#define APP_NAME "ATMOSCAN"

// Syslog server connection info (IP is from configuration portal)
#define SYSLOG_PORT 514

// I/O pins assignments
#define VOC_PIN A0
#define I2C_SDA_PIN 4
#define I2C_SCL_PIN 5
#define GESTURE_INTERRUPT_PIN 10
#define GEIGER_INTERRUPT_PIN 15
#define CO2_RX_PIN 0
#define CO2_TX_PIN 2
#define BACKLIGHT_PIN 12 // NOTE: Active low
#define KILL_PIN 9 // NOTE: Requires PCB v2.0 or mod!!

#define BACKLIGHT_TIMEOUT 60000 // millisec
#define CONFIG_PORTAL_TIMEOUT 600 // sec

#define START_SCREEN 1
#define SETUP_SCREEN 0
#define LOWBATT_SCREEN 99
#define TOP_BAR_HEIGHT 64

// RUNTIME definitions (NOTE: _VERY_ empirical, depends on battery!)
#define VOLT_LOW 3.3
#define VOLT_HIGH 4.15

#define AVERAGING_WINDOW 12         // NOTE: 12 * 5 sec sensor sampling rate = 1 minute

#define FAST_SAMPLE_PERIOD 2500     // (ms) Used for Geiger sensor 
#define SLOW_SAMPLE_PERIOD 5000     // (ms) Used for other sensors 
#define MQTT_UPDATE_PERIOD 60000    // (ms)
#define GEOLOC_RETRY_PERIOD 60000   // (ms)

// -------------------------------------------------------
//  Global constants
// -------------------------------------------------------

// NTP Server - TODO: move into configuration?
const char PROGMEM ntpServerName[] = "time.google.com";

// Constants
const char PROGMEM empty[] = "";

// -------------------------------------------------------
//  Types
// -------------------------------------------------------

// Holds pointers to processes
struct ProcessContainer
{
  // Members

  Proc_ComboTemperatureHumiditySensor ComboTemperatureHumiditySensor ;
  Proc_ComboPressureHumiditySensor ComboPressureHumiditySensor;
  Proc_CO2Sensor CO2Sensor;
  Proc_ParticleSensor ParticleSensor;
  Proc_VOCSensor VOCSensor;
  Proc_MultiGasSensor MultiGasSensor;
  Proc_GeigerSensor GeigerSensor;
  Proc_UIManager UIManager;
  Proc_MQTTUpdate MQTTUpdate;
  Proc_GeoLocation GeoLocation;

};

// Holds various items related to the current configuration
struct Configuration
{
  bool configValid;
  bool connected = false;
  int startScreen = START_SCREEN;
  char mqtt_topic1[64];
  char mqtt_topic2[64];
  char mqtt_topic3[64];
  char mqtt_server[40];
  char syslog_server[20];

  char google_key[64];
  char wunderground_key[64];
  char  geonames_user[32];
  char  timezonedb_key[64];
};

/*
  // Configuration management parameters
  const char PROGMEM mqtt_server[]  = "MQTT_Server";
  const char PROGMEM mqtt_topic1[]  = "MQTT_Topic1";
  const char PROGMEM mqtt_topic2[]  = "MQTT_Topic2";
  const char PROGMEM mqtt_topic3[]  = "MQTT_Topic3";
  const char PROGMEM syslog_server[]  = "Syslog_Server";
  const char PROGMEM google_key[]  = "google_key";
  const char PROGMEM wunderground_key[]  = "Wunderground_Key";
  const char PROGMEM geonames_user[]   = "Geonames_User";
  const char PROGMEM timezonedb_key[]  = "Timezonedb_Key";
*/

#endif

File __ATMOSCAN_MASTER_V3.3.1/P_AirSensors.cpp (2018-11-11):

/********************************************************/
/*                    ATMOSCAN                          */
/*                                                      */
/*            Author: Marc Finns 2017                   */
/*                                                      */
/********************************************************/

#include <ProcessScheduler.h>     // https://github.com/wizard97/ArduinoProcessScheduler
#include <Syslog.h>                 // https://github.com/arcao/ESP8266_Syslog
#include <Adafruit_BME280.h>        // https://github.com/adafruit/Adafruit_BME280_Library NOTE: Requires https://github.com/adafruit/Adafruit_Sensor
#include <MutichannelGasSensor.h>   // https://github.com/MarcFinns/Mutichannel_Gas_Sensor

#include "P_AirSensors.h"
#include "GlobalDefinitions.h"

// External variables
extern Syslog syslog;
extern struct ProcessContainer procPtr;
extern struct Configuration config;

extern TFT_eSPI LCD;


// Prototypes
void errLog(String msg);

// Geiger tube definitions
#define LND712_CONV_FACTOR  123 // CPS * 1/123 = uSv/h

// Particle sensor PMS7003 definitions
#define PMS7003_COMMAND_SIZE 7
#define PMS7003_RESPONSE_SIZE 32

// CO2 Sensor MH-Z19 definitions
#define MHZ19_COMMAND_SIZE 9
#define MHZ19_RESPONSE_SIZE 9

// Temperature sensor definitions
#define TEMPERATURE_ADJUSTMENT_FACTOR -0.4 // NOTE: empirical correction based on observations, TBC

// Particle sensor PMS7003 definitions
static const byte PMS7003_cmdPassiveEnable[] = {0x42, 0x4d, 0xe1, 0x00, 0x00, 0x01, 0x70};
static const byte PMS7003_cmdPassiveRead[] = {0x42, 0x4d, 0xe2, 0x00, 0x00, 0x01, 0x71};
static const byte PMS7003_cmdSleep[] = {0x42, 0x4d, 0xe4, 0x00, 0x00, 0x01, 0x73};
static const byte PMS7003_cmdWakeup[] = {0x42, 0x4d, 0xe4, 0x00, 0x01, 0x01, 0x74};

// CO2 Sensor MH-Z19 definitions
static const byte MHZ19_cmdRead[9] = {0xFF, 0x01, 0x86, 0x00, 0x00, 0x00, 0x00, 0x00, 0x79};

// Sensor processes implementation

// -------------------------------------------------------
// Combo Temperature & Umidity Sensor wrapper (HDC1080)
// -------------------------------------------------------

Proc_ComboTemperatureHumiditySensor::Proc_ComboTemperatureHumiditySensor(Scheduler &manager, ProcPriority pr, unsigned int period, int iterations)
  :  Process(manager, pr, period, iterations),
     avgTemperature(AVERAGING_WINDOW),
     avgHumidity(AVERAGING_WINDOW) {}

void Proc_ComboTemperatureHumiditySensor::setup()
{

#ifdef DEBUG_SYSLOG
  syslog.log(LOG_DEBUG, "Proc_ComboTemperatureHumiditySensor::setup()");
#endif

  //  Sensor begin
  hdc1080.begin(0x40);

#ifdef DEBUG_SYSLOG
  syslog.log(LOG_INFO, "Manufacturer ID=" + String((hdc1080.readManufacturerId(), HEX)));  // 0x5449 ID of Texas Instruments
  syslog.log(LOG_INFO, "Device ID=" + String((hdc1080.readDeviceId(), HEX)));  // 0x1050 ID of the device
#endif

  // Is the device reachable?
  if (!(hdc1080.readDeviceId() == 0x1050))
  {
    // There was a problem detecting the sensor
    errLog(F("Err HDC1080 - disabled"));

    // Set invalid reading
    avgTemperature.push(0);
    avgHumidity.push(0);

    // Disable process
    this->disable();
  }

  // first reading, to initialise averages

  // Get temperature value
  float temp = hdc1080.readTemperature();

  // initialize average
  avgTemperature.push(temp + TEMPERATURE_ADJUSTMENT_FACTOR);


  // Get humidity value
  float hum = hdc1080.readHumidity();

  // initialize average
  avgHumidity.push(hum);

}

void Proc_ComboTemperatureHumiditySensor::service()
{
#ifdef DEBUG_SYSLOG
  syslog.log(LOG_DEBUG, "Proc_ComboTemperatureHumiditySensor::service()");
#endif

  // Get temperature value
  float temp = hdc1080.readTemperature();

  // If sensor misbehave (might happen when battery is drained), reset it and skip a reading cycle
  // Misbehavior is define as a jump in value of more than 5 degree in 5 seconds with respect to the moving average
  if (abs(temp - avgTemperature.mean()) > 5 )
  {
    // Log error
    errLog(F("TemperatureHumiditySensor - Temp error - resetting sensor"));
    syslog.log(LOG_ERR, String(F("Temp reading was =")) + String(temp));
    syslog.log(LOG_ERR, String(F("Battery voltage was =")) + String(procPtr.UIManager.getVolt()));

    //  Reset Sensor
    hdc1080.begin(0x40);

    // Skip cycle
    return;
  }


  // Get humidity value
  float humidity = hdc1080.readHumidity();

  // If sensor misbehave (might happen when battery is drained), reset it and skip a reading cycle
  // Misbehavior is define as a jump in value of more than 10% in 5 seconds with respect to the moving average
  if (abs(humidity - avgHumidity.mean()) > 10 )
  {
    // Log error
    errLog(F("TemperatureHumiditySensor - Humidity error - resetting sensor"));
    syslog.log(LOG_ERR, String(F("Hum reading was =")) + String(humidity));
    syslog.log(LOG_ERR, String(F("Battery voltage was =")) + String(procPtr.UIManager.getVolt()));

    //  Reset Sensor
    hdc1080.begin(0x40);

    // Skip cycle
    return;
  }

  // averages
  avgTemperature.push(temp + TEMPERATURE_ADJUSTMENT_FACTOR);
  avgHumidity.push(humidity);

}

float Proc_ComboTemperatureHumiditySensor::getTemperature()
{
  return avgTemperature.mean();
}

float Proc_ComboTemperatureHumiditySensor::getHumidity()
{
  return avgHumidity.mean();
}
// END Combo Temperature & Umidity Sensor wrapper (HDC1080)


// -------------------------------------------------------
// Combo Pressure & humidity Sensor process (BME280)
// -------------------------------------------------------

Proc_ComboPressureHumiditySensor::Proc_ComboPressureHumiditySensor(Scheduler &manager, ProcPriority pr, unsigned int period, int iterations)
  :  Process(manager, pr, period, iterations),
     avgPressure(AVERAGING_WINDOW),
     avgHumidity(AVERAGING_WINDOW),
     avgTemperature(AVERAGING_WINDOW)
{
}
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

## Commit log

2018-04-24 Move sketch to appropriately named subfolder
    The Arduino IDE requires that a sketch be located in a folder of the same name. When opening a file that does not meet this sketch/folder name matching requirement the Arduino IDE presents a dialog:
    The file "__ATMOSCAN_MASTER_V2.0.ino" needs to be inside a sketch folder named "__ATMOSCAN_MASTER_V2.0".
    Create this folder, move the file, and continue?
    After clicking "OK" the Arduino IDE currently moves only the file __ATMOSCAN_MASTER_V2.0.ino to the new folder, leaving behind the other source files. This causes compilation of the sketch to fail:
    __ATMOSCAN_MASTER_V2.0.ino:1:67: fatal error: GlobalDefinitions.h: No such file or directory
    #inclu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
    [AdsbExchangeClient.cpp, Geocode.cpp]
2018-05-11 V2.2
    1. If sensors are not present/connected, they just appear disabled and the rest should work (did not test all combinations)
    2. Added an I2C scan that SYSLOGs the IDs of all devices connected to the bus. Useful for first build. Enabled when compiling with DEBUG_SYSLOG defined
    Hope it helps.
2018-06-05 REL 2.3
    2.3 Release notes
    Turn off mod - allows the sketch to turn off the device, either from a command or when battery low (REQUIRES MINOR HW MOD)
    Sensors scan - those not present are disabled and boot continues
    Case fix - file names fixed to allow compilation on Linux
    NOTE: on some platforms the ESP8266 built-in SoftwareSerial support cannot be overridden by the user-level library (newer) and must be removed
    [AdsbExchangeClient.cpp, Geocode.cpp]
2018-06-06 Updated hardware
    V2 PCB and how to implement mods to V1
    [Atmoscan-ng.brd, Atmoscan-ng.sch, Atmoscan-ng_TURNOFF.brd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]
2018-06-06 Full enclosure
    CAD files for full enclosure
2018-06-09 small fixes
    [Atmoscan-ng_TURNOFF.sch]
2018-06-10 Must read comments on PCB V2
2018-06-10 Battery management
    Better averages for SoC and voltage, to take into account fluctuations because of sensors current peaks
2018-06-10 New battery back
    5 X 18650 in olympic-style arrangement
2018-06-11 Compatibility with latest TFT library
    workaround for now
    [AdsbExchangeClient.cpp, Geocode.cpp]
2018-10-14 Bug fixing
    Better SPIFFS fragmentation management
    [AdsbExchangeClient.cpp, Geocode.cpp]
2018-10-14 Fixed SPIFFS fragmentation issues
    [ScreenBuienRadar.cpp]
2018-11-11 Corrected a bug on sensor init logic
    Corrected a bug on sensor init logic
    [GlobalDefinitions.h, P_AirSensors.cpp]

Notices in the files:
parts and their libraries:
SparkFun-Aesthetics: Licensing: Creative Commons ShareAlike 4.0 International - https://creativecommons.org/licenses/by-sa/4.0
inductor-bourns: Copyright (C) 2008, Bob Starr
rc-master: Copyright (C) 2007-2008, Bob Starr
